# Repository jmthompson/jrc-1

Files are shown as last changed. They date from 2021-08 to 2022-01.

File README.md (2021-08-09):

JRC-1
=====

The JRC-1 (Josh's Retro Computer 1) the first in my new series of homebrew
retro computers. It is the first in the JRC series and is the successor to
COLE-1 and COLE-2.

The primary goal for this project is to scale back some of the lofty goals set
for its predecessor, and instead provide some limited expansion capabilities
so that features can be added iteratively down the road.

More information is available on the JRC-1 section of my blog at
https://www.area73.us/jrc-1.

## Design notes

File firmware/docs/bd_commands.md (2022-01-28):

Block Device Commands
=====================

[I] = input parameter
[O] = output parameter

* INIT ($01)

no command block

* STATUS ($02)

    0 : [O] status, 1 = online, 0 = offline
  1-4 : [O] unit size in blocks
 5-31 : [O] unit name, null-terminated

* MOUNT ($03)

no command block

* EJECT ($04)

no command block

* FORMAT ($05)

no command block

* READ_BLOCK ($06)

0-4 : [I] block number 
5-8 : [I] block buffer pointer

* WRITE_BLOCK ($07)

0-4 : [I] block number 
5-8 : [I] block buffer pointer

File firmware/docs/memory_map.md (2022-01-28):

JRC-1 Memory Map
================

|--------------------------------| $00/0000
|         Base RAM (60K)         |
|--------------------------------| $00/F000
|         I/O Area (2K)          |
|--------------------------------| $00/F800
|         Boot ROM (2K)          |
|--------------------------------| $01/0000
|      Extended RAM (944K)       |
|--------------------------------| $0F/C000
|        Video RAM (16K)         |
|--------------------------------| $10/0000
|       System ROM (256K)        |
|--------------------------------| $14/0000

Due to the way the hardware maps the ROM into the processor address space, the
boot ROM area from $00/F800-FFFF also appears at $10/F800-FFFF. This is where
the code "really" lives in the EEPROM image.

The space in banks $14-$1F are dead space, and will usually just read back as
containing the bank number byte at all locations. At bank $20 and beyond the
memory map just repeats, as A21-A23 are not decoded by the hardware.

* Bank 0

$0000 - $CFFF : [ unused, available for application use ]
$D000 - $E6FF : System buffers
$E700 - $E7FF : System direct page
$E800 - $EFFF : System stack
$F000 - $F7FF : I/O (see table below)
$F800 - $FFFF : Boot ROM (boot/interrupt vectors, I/O drivers)

The I/O is divided into eight 256-byte pages. For each page $FnXX the
value n corresponds to a slot number from 0-7. Slot 0 is for on-board
devices, 1-3 are the three slots on the board, and 4-7 are currently
reserved.

The on-board devices are assigne 16-byte I/O windows in the slot 0 space
as follows:

$F000 - $F00F : VIA
$F010 - $F01F : SPI
$F020 - $F02F : UART

All other space is reserved.

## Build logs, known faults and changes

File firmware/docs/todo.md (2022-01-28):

TODO
====

This is just a scratch space for me to write down things that need
fixed or updated.

- Make BRK handler jump through a RAM vector that we default to being monitor_brk
- Make NMI handler jump through a RAM vector that we default to being monitor_nmi
- Add a user-settable vector for via_irq (or maybe one per interrupt source)

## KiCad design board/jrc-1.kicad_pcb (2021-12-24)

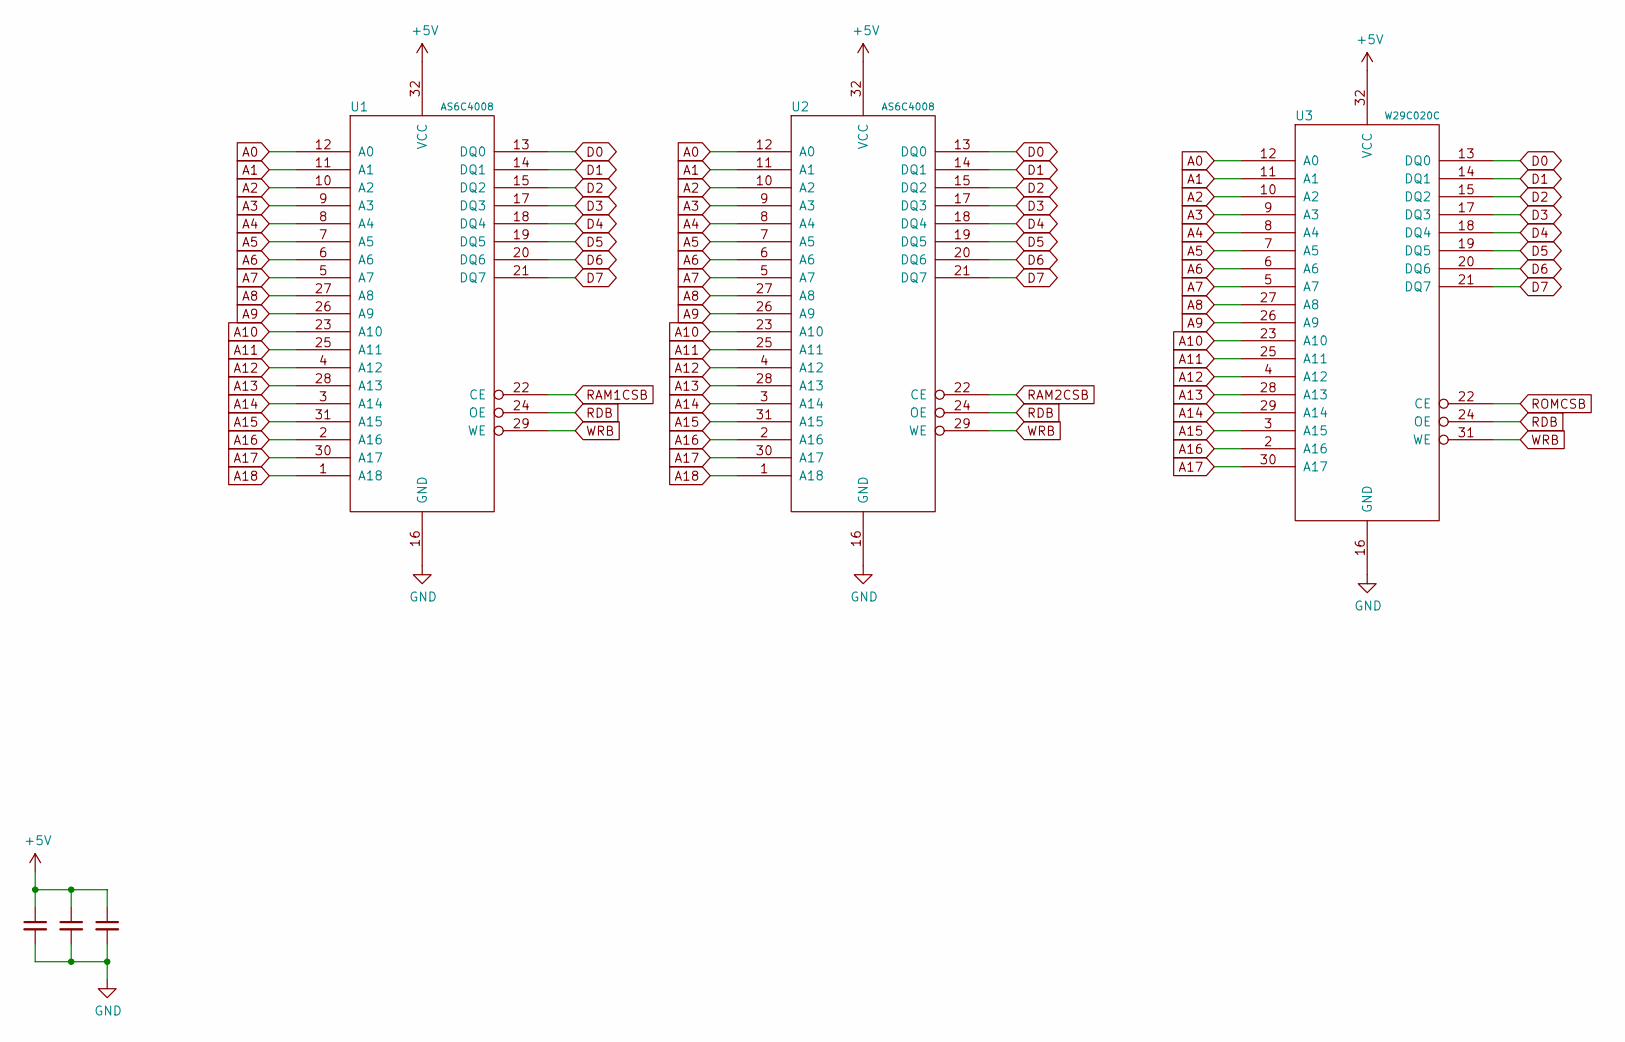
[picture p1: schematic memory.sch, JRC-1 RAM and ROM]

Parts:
C1, C2, C3: 0.1u; C_Rect_L4.6mm_W2.0mm_P2.50mm_MKS02_FKP02
U1, U2: AS6C4008; DIP-32_W15.24mm_Socket
U3: W29C020C; DIP_Socket-32_W11.9_W12.7_W15.24_W17.78_W18.5_3M_232-1285-0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

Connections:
+5V: C1.1, C2.1, C3.1, U1.32 (VCC), U2.32 (VCC), U3.32 (VCC); also elsewhere on the board
A0: U1.12 (A0), U2.12 (A0), U3.12 (A0); also elsewhere on the board
A1: U1.11 (A1), U2.11 (A1), U3.11 (A1); also elsewhere on the board
A2: U1.10 (A2), U2.10 (A2), U3.10 (A2); also elsewhere on the board
A3: U1.9 (A3), U2.9 (A3), U3.9 (A3); also elsewhere on the board
A4: U1.8 (A4), U2.8 (A4), U3.8 (A4); also elsewhere on the board
A5: U1.7 (A5), U2.7 (A5), U3.7 (A5); also elsewhere on the board
A6: U1.6 (A6), U2.6 (A6), U3.6 (A6); also elsewhere on the board
A7: U1.5 (A7), U2.5 (A7), U3.5 (A7); also elsewhere on the board
A8: U1.27 (A8), U2.27 (A8), U3.27 (A8); also elsewhere on the board
A9: U1.26 (A9), U2.26 (A9), U3.26 (A9); also elsewhere on the board
A10: U1.23 (A10), U2.23 (A10), U3.23 (A10); also elsewhere on the board
A11: U1.25 (A11), U2.25 (A11), U3.25 (A11); also elsewhere on the board
A12: U1.4 (A12), U2.4 (A12), U3.4 (A12); also elsewhere on the board
A13: U1.28 (A13), U2.28 (A13), U3.28 (A13); also elsewhere on the board
A14: U1.3 (A14), U2.3 (A14), U3.29 (A14); also elsewhere on the board
A15: U1.31 (A15), U2.31 (A15), U3.3 (A15); also elsewhere on the board
A16: U1.2 (A16), U2.2 (A16), U3.2 (A16); also elsewhere on the board
A17: U1.30 (A17), U2.30 (A17), U3.30 (A17); also elsewhere on the board
A18: U1.1 (A18), U2.1 (A18); also elsewhere on the board
D0: U1.13 (DQ0), U2.13 (DQ0), U3.13 (DQ0); also elsewhere on the board
D1: U1.14 (DQ1), U2.14 (DQ1), U3.14 (DQ1); also elsewhere on the board
D2: U1.15 (DQ2), U2.15 (DQ2), U3.15 (DQ2); also elsewhere on the board
D3: U1.17 (DQ3), U2.17 (DQ3), U3.17 (DQ3); also elsewhere on the board
D4: U1.18 (DQ4), U2.18 (DQ4), U3.18 (DQ4); also elsewhere on the board
D5: U1.19 (DQ5), U2.19 (DQ5), U3.19 (DQ5); also elsewhere on the board
D6: U1.20 (DQ6), U2.20 (DQ6), U3.20 (DQ6); also elsewhere on the board
D7: U1.21 (DQ7), U2.21 (DQ7), U3.21 (DQ7); also elsewhere on the board
GND: C1.2, C2.2, C3.2, U1.16 (GND), U2.16 (GND), U3.16 (GND); also elsewhere on the board
RAM1CSB: U1.22 (CE); also elsewhere on the board
RAM2CSB: U2.22 (CE); also elsewhere on the board
RDB: U1.24 (OE), U2.24 (OE), U3.24 (OE); also elsewhere on the board
ROMCSB: U3.22 (CE); also elsewhere on the board
WRB: U1.29 (WE), U2.29 (WE), U3.31 (WE); also elsewhere on the board

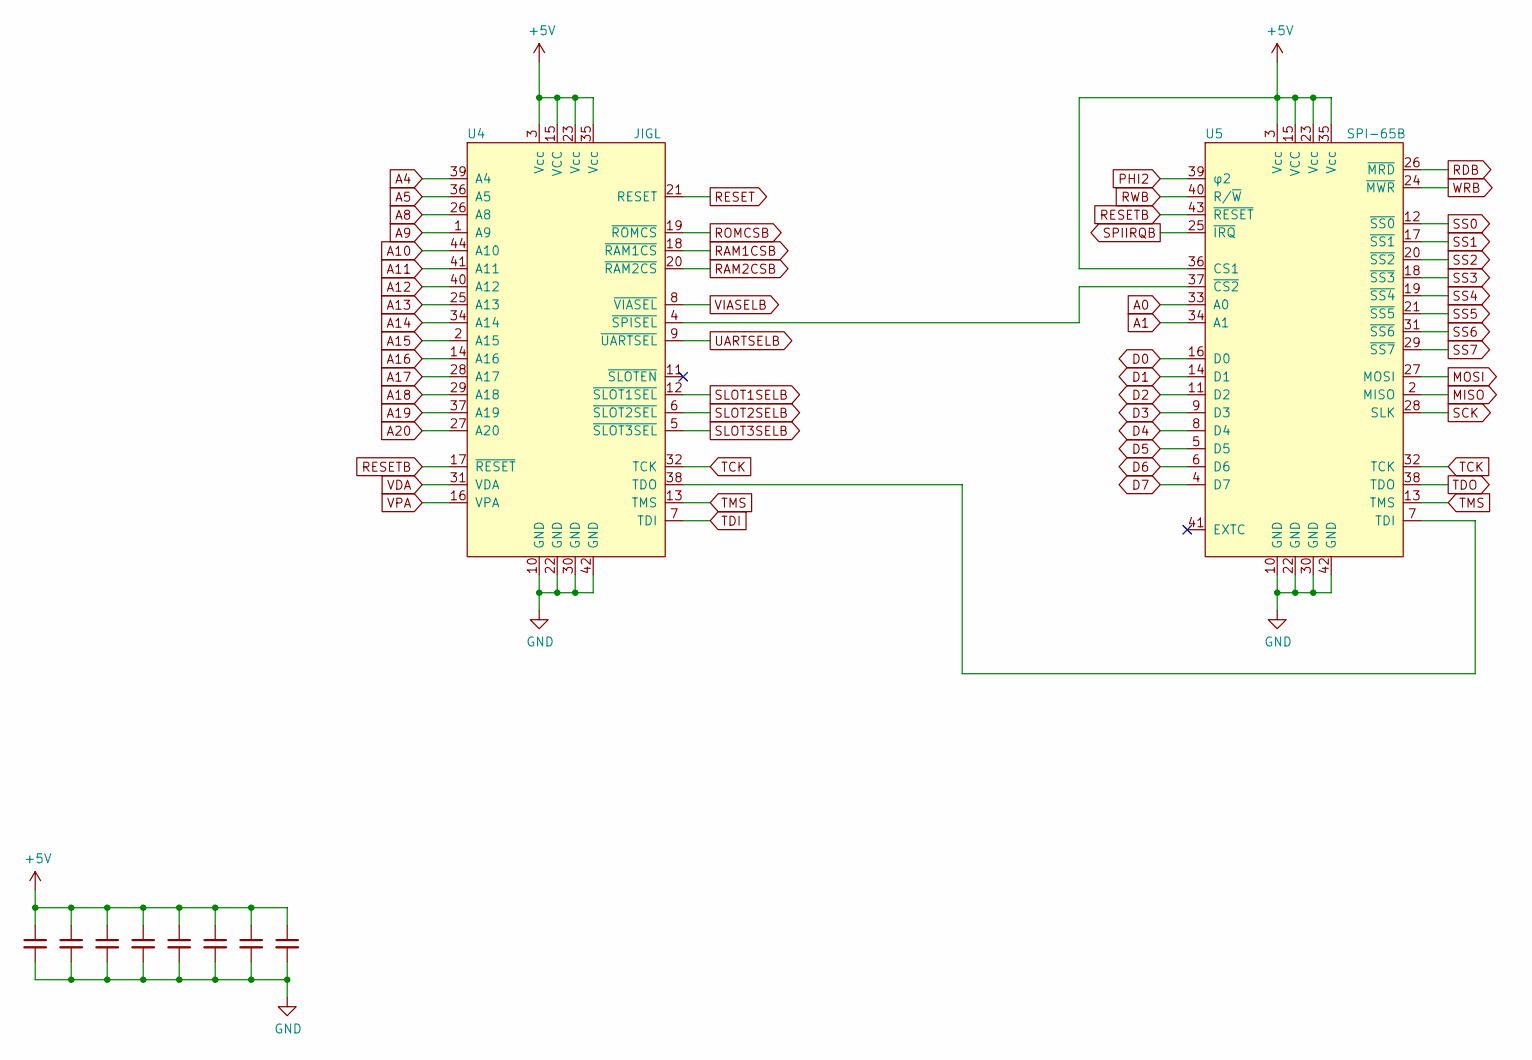
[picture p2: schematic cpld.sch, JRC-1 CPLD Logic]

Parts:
C4, C5, C6, C7, C8, C9, C10, C11: 0.1u; C_Rect_L4.6mm_W2.0mm_P2.50mm_MKS02_FKP02
U4: JIGL; PLCC-44_THT-Socket
U5: SPI-65B; PLCC-44_THT-Socket

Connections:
+5V: C4.1, C5.1, C6.1, C7.1, C8.1, C9.1, C10.1, C11.1, U4.3 (Vcc), U4.15 (VCC), U4.23 (Vcc), U4.35 (Vcc), U5.3 (Vcc), U5.15 (VCC), U5.23 (Vcc), U5.35 (Vcc), U5.36 (CS1); also elsewhere on the board
A0: U5.33 (A0); also elsewhere on the board
A1: U5.34 (A1); also elsewhere on the board
A4: U4.39 (A4); also elsewhere on the board
A5: U4.36 (A5); also elsewhere on the board
A8: U4.26 (A8); also elsewhere on the board
A9: U4.1 (A9); also elsewhere on the board
A10: U4.44 (A10); also elsewhere on the board
A11: U4.41 (A11); also elsewhere on the board
A12: U4.40 (A12); also elsewhere on the board
A13: U4.25 (A13); also elsewhere on the board
A14: U4.34 (A14); also elsewhere on the board
A15: U4.2 (A15); also elsewhere on the board
A16: U4.14 (A16); also elsewhere on the board
A17: U4.28 (A17); also elsewhere on the board
A18: U4.29 (A18); also elsewhere on the board
A19: U4.37 (A19); also elsewhere on the board
A20: U4.27 (A20); also elsewhere on the board
D0: U5.16 (D0); also elsewhere on the board
D1: U5.14 (D1); also elsewhere on the board
D2: U5.11 (D2); also elsewhere on the board
D3: U5.9 (D3); also elsewhere on the board
D4: U5.8 (D4); also elsewhere on the board
D5: U5.5 (D5); also elsewhere on the board
D6: U5.6 (D6); also elsewhere on the board
D7: U5.4 (D7); also elsewhere on the board
GND: C4.2, C5.2, C6.2, C7.2, C8.2, C9.2, C10.2, C11.2, U4.10 (GND), U4.22 (GND), U4.30 (GND), U4.42 (GND), U5.10 (GND), U5.22 (GND), U5.30 (GND), U5.42 (GND); also elsewhere on the board
MISO: U5.2 (MISO); also elsewhere on the board
MOSI: U5.27 (MOSI); also elsewhere on the board
unnamed: U4.4 (~SPISEL), U5.37 (~CS2)
unnamed: U4.38 (TDO), U5.7 (TDI)
PHI2: U5.39 (φ2); also elsewhere on the board
RAM1CSB: U4.18 (~RAM1CS); also elsewhere on the board
RAM2CSB: U4.20 (~RAM2CS); also elsewhere on the board
RDB: U5.26 (~MRD); also elsewhere on the board
RESET: U4.21 (RESET); also elsewhere on the board
RESETB: U4.17 (~RESET), U5.43 (~RESET); also elsewhere on the board
ROMCSB: U4.19 (~ROMCS); also elsewhere on the board
RWB: U5.40 (R/~W); also elsewhere on the board
SCK: U5.28 (SLK); also elsewhere on the board
SLOT1SELB: U4.12 (~SLOT1SEL); also elsewhere on the board
SLOT2SELB: U4.6 (~SLOT2SEL); also elsewhere on the board
SLOT3SELB: U4.5 (~SLOT3SEL); also elsewhere on the board
SPIIRQB: U5.25 (~IRQ); also elsewhere on the board
SS0: U5.12 (~SS0); also elsewhere on the board
SS1: U5.17 (~SS1); also elsewhere on the board
SS2: U5.20 (~SS2); also elsewhere on the board
SS3: U5.18 (~SS3); also elsewhere on the board
SS4: U5.19 (~SS4); also elsewhere on the board
SS5: U5.21 (~SS5); also elsewhere on the board
SS6: U5.31 (~SS6); also elsewhere on the board
SS7: U5.29 (~SS7); also elsewhere on the board
TCK: U4.32 (TCK), U5.32 (TCK); also elsewhere on the board
TDI: U4.7 (TDI); also elsewhere on the board
TDO: U5.38 (TDO); also elsewhere on the board
TMS: U4.13 (TMS), U5.13 (TMS); also elsewhere on the board
UARTSELB: U4.9 (~UARTSEL); also elsewhere on the board
VDA: U4.31 (VDA); also elsewhere on the board
VIASELB: U4.8 (~VIASEL); also elsewhere on the board
VPA: U4.16 (VPA); also elsewhere on the board
WRB: U5.24 (~MWR); also elsewhere on the board

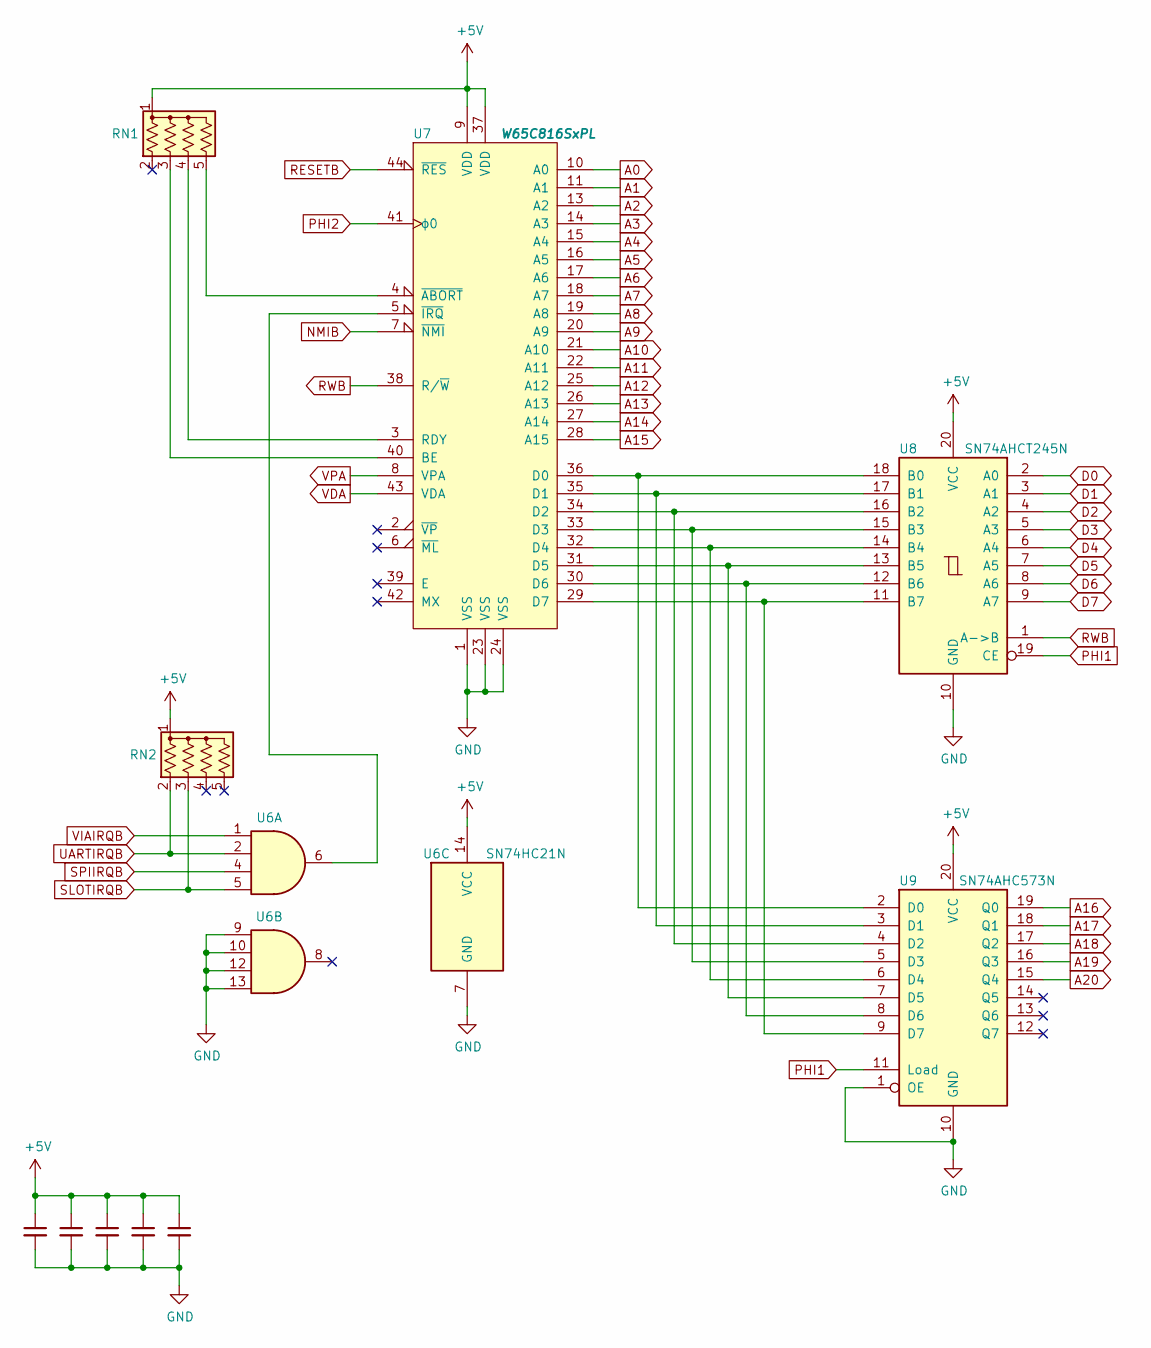
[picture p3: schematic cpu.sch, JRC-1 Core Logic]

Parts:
C12, C13, C14, C15, C16: 0.1u; C_Rect_L4.6mm_W2.0mm_P2.50mm_MKS02_FKP02
RN1, RN2: 4605X-101-332LF; R_Array_SIP5
U6: SN74HC21N; DIP-14_W7.62mm_Socket
U7: W65C816SxPL; PLCC-44_THT-Socket
U8: SN74AHCT245N; DIP-20_W7.62mm_Socket
U9: SN74AHC573N; DIP-20_W7.62mm_Socket

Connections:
+5V: C12.1, C13.1, C14.1, C15.1, C16.1, RN1.1 (common), RN2.1 (common), U6.14 (VCC), U7.9 (VDD), U7.37 (VDD), U8.20 (VCC), U9.20 (VCC); also elsewhere on the board
A0: U7.10 (A0); also elsewhere on the board
A1: U7.11 (A1); also elsewhere on the board
A2: U7.13 (A2); also elsewhere on the board
A3: U7.14 (A3); also elsewhere on the board
A4: U7.15 (A4); also elsewhere on the board
A5: U7.16 (A5); also elsewhere on the board
A6: U7.17 (A6); also elsewhere on the board
A7: U7.18 (A7); also elsewhere on the board
A8: U7.19 (A8); also elsewhere on the board
A9: U7.20 (A9); also elsewhere on the board
A10: U7.21 (A10); also elsewhere on the board
A11: U7.22 (A11); also elsewhere on the board
A12: U7.25 (A12); also elsewhere on the board
A13: U7.26 (A13); also elsewhere on the board
A14: U7.27 (A14); also elsewhere on the board
A15: U7.28 (A15); also elsewhere on the board
A16: U9.19 (Q0); also elsewhere on the board
A17: U9.18 (Q1); also elsewhere on the board
A18: U9.17 (Q2); also elsewhere on the board
A19: U9.16 (Q3); also elsewhere on the board
A20: U9.15 (Q4); also elsewhere on the board
D0: U8.2 (A0); also elsewhere on the board
D1: U8.3 (A1); also elsewhere on the board
D2: U8.4 (A2); also elsewhere on the board
D3: U8.5 (A3); also elsewhere on the board
D4: U8.6 (A4); also elsewhere on the board
D5: U8.7 (A5); also elsewhere on the board
D6: U8.8 (A6); also elsewhere on the board
D7: U8.9 (A7); also elsewhere on the board
GND: C12.2, C13.2, C14.2, C15.2, C16.2, U6.7 (GND), U6.9, U6.10, U6.12, U6.13, U7.1 (VSS), U7.23 (VSS), U7.24 (VSS), U8.10 (GND), U9.1 (OE), U9.10 (GND); also elsewhere on the board
NMIB: U7.7 (~NMI); also elsewhere on the board
unnamed: RN1.3 (R2), U7.40 (BE)
unnamed: RN1.4 (R3), U7.3 (RDY)
unnamed: RN1.5 (R4), U7.4 (~ABORT)
unnamed: U6.6, U7.5 (~IRQ)
unnamed: U7.29 (D7), U8.11 (B7), U9.9 (D7)
unnamed: U7.30 (D6), U8.12 (B6), U9.8 (D6)
unnamed: U7.31 (D5), U8.13 (B5), U9.7 (D5)
unnamed: U7.32 (D4), U8.14 (B4), U9.6 (D4)
unnamed: U7.33 (D3), U8.15 (B3), U9.5 (D3)
unnamed: U7.34 (D2), U8.16 (B2), U9.4 (D2)
unnamed: U7.35 (D1), U8.17 (B1), U9.3 (D1)
unnamed: U7.36 (D0), U8.18 (B0), U9.2 (D0)
PHI1: U8.19 (CE), U9.11 (Load); also elsewhere on the board
PHI2: U7.41 (ϕ0); also elsewhere on the board
RESETB: U7.44 (~RES); also elsewhere on the board
RWB: U7.38 (R/~W), U8.1 (A->B); also elsewhere on the board
SLOTIRQB: RN2.3 (R2), U6.5; also elsewhere on the board
SPIIRQB: U6.4; also elsewhere on the board
UARTIRQB: RN2.2 (R1), U6.2; also elsewhere on the board
VDA: U7.43 (VDA); also elsewhere on the board
VIAIRQB: U6.1; also elsewhere on the board
VPA: U7.8 (VPA); also elsewhere on the board

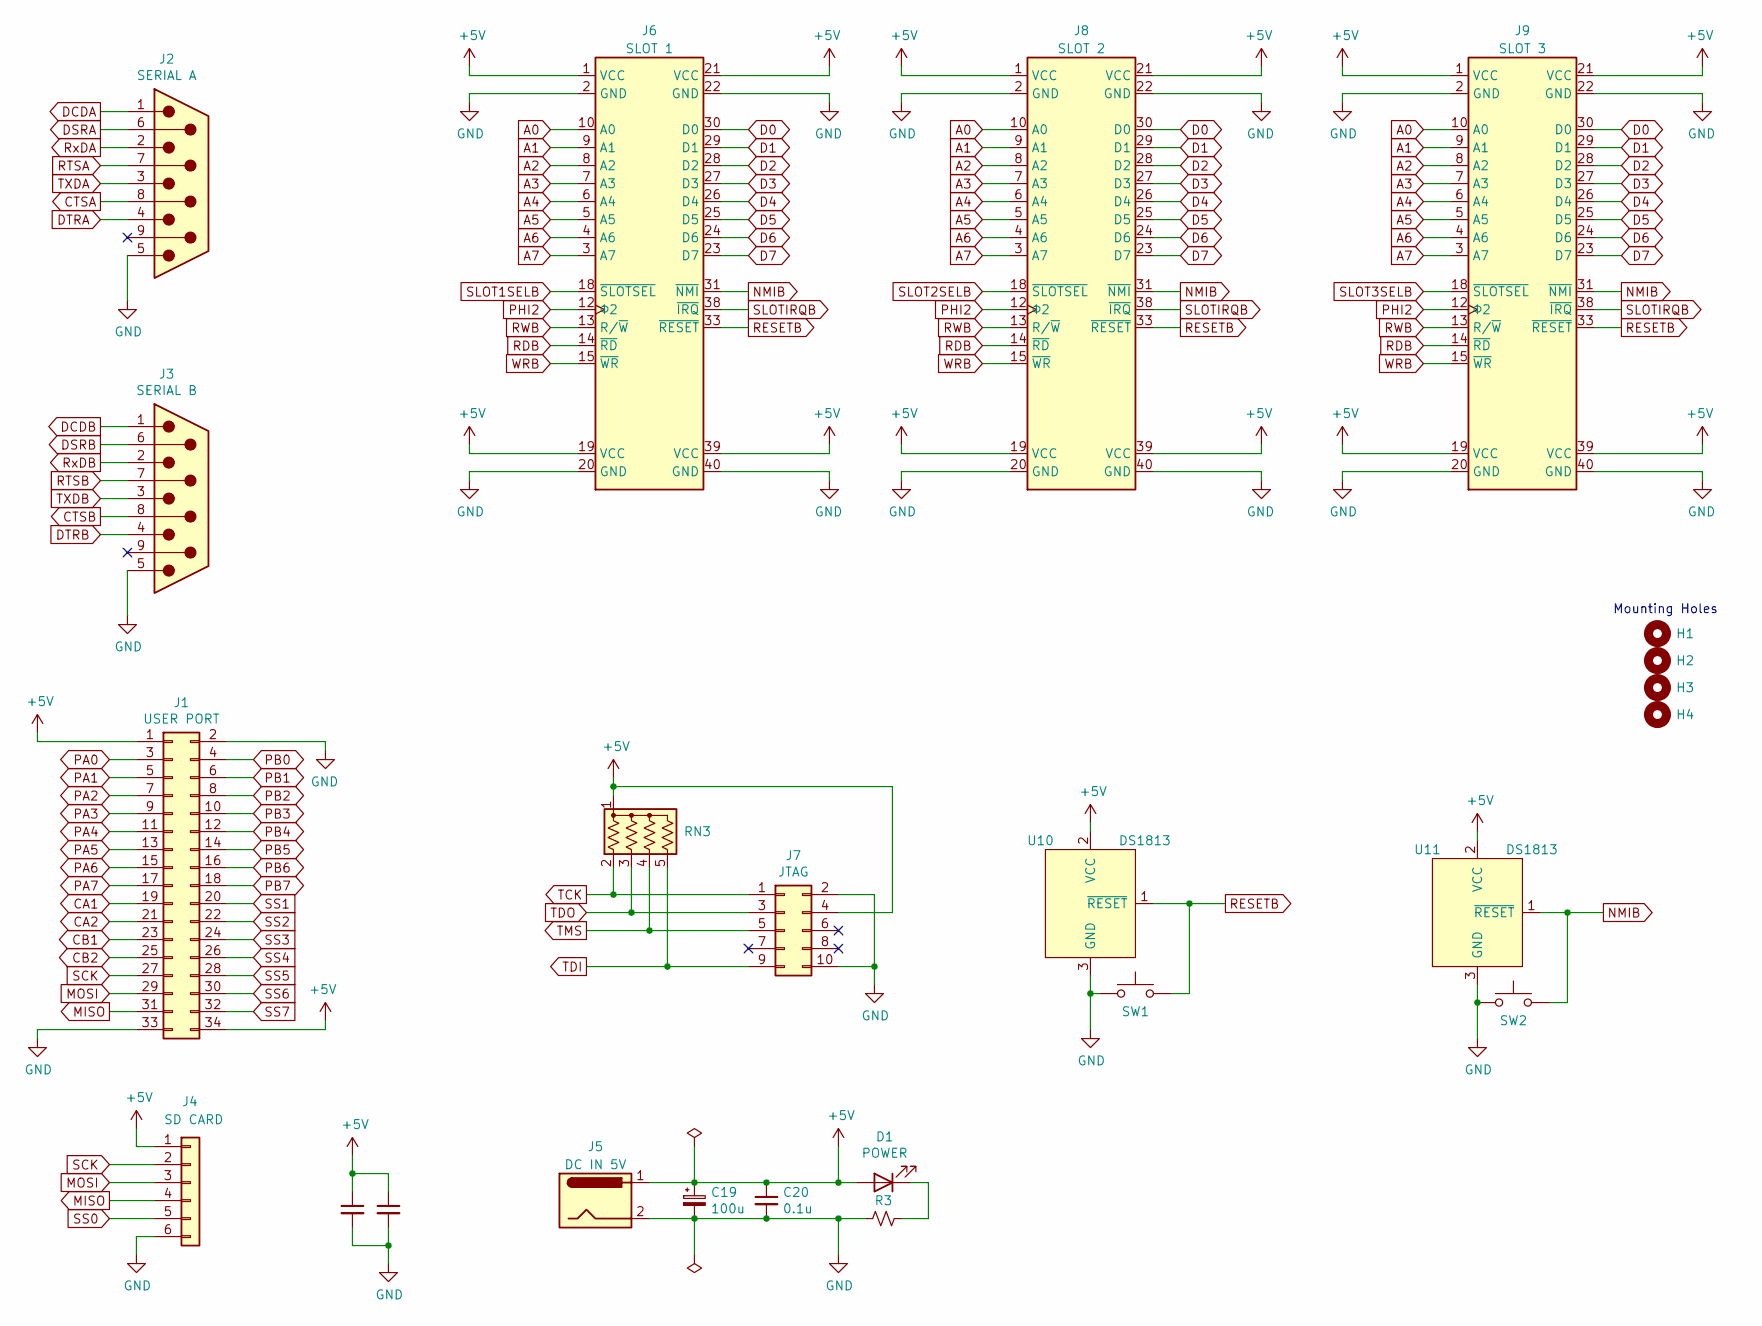
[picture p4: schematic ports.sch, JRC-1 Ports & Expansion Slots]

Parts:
C17, C18, C20: 0.1u; C_Rect_L4.6mm_W2.0mm_P2.50mm_MKS02_FKP02
C19: 100u; CP_Radial_D6.3mm_P2.50mm
D1: POWER; LED_D5.0mm_Clear
H1, H2, H3, H4: MountingHole; MountingHole_2.7mm_M2.5
J1: USER PORT; PinHeader_2x17_P2.54mm_Vertical
J2: SERIAL A; DSUB-9_Male_Horizontal_P2.77x2.84mm_EdgePinOffset4.94mm_Hou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
J3: SERIAL B; DSUB-9_Male_Horizontal_P2.77x2.84mm_EdgePinOffset4.94mm_Hou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
J4: SD CARD; PinHeader_1x06_P2.54mm_Vertical
J5: DC IN 5V; BarrelJack_Horizontal
J6: SLOT 1; JRC_Expansion_Slot
J7: JTAG; IDC-Header_2x05_P2.54mm_Vertical
J8: SLOT 2; JRC_Expansion_Slot
J9: SLOT 3; JRC_Expansion_Slot
R3: 330; R_Axial_DIN0207_L6.3mm_D2.5mm_P10.16mm_Horizontal
RN3: 4605X-101-472LF; R_Array_SIP5
SW1: RESET; SW_PUSH_6mm_H5mm
SW2: NMI; SW_PUSH_6mm_H5mm
U10, U11: DS1813; TO-92

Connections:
+5V: C17.1, C18.1, C19.1, C20.1, D1.2 (A), J1.1, J1.34, J4.1, J5.1, J6.1 (VCC), J6.19 (VCC), J6.21 (VCC), J6.39 (VCC), J7.4, J8.1 (VCC), J8.19 (VCC), J8.21 (VCC), J8.39 (VCC), J9.1 (VCC), J9.19 (VCC), J9.21 (VCC), J9.39 (VCC), RN3.1 (common), U10.2 (VCC), U11.2 (VCC); also elsewhere on the board
A0: J6.10 (A0), J8.10 (A0), J9.10 (A0); also elsewhere on the board
A1: J6.9 (A1), J8.9 (A1), J9.9 (A1); also elsewhere on the board
A2: J6.8 (A2), J8.8 (A2), J9.8 (A2); also elsewhere on the board
A3: J6.7 (A3), J8.7 (A3), J9.7 (A3); also elsewhere on the board
A4: J6.6 (A4), J8.6 (A4), J9.6 (A4); also elsewhere on the board
A5: J6.5 (A5), J8.5 (A5), J9.5 (A5); also elsewhere on the board
A6: J6.4 (A6), J8.4 (A6), J9.4 (A6); also elsewhere on the board
A7: J6.3 (A7), J8.3 (A7), J9.3 (A7); also elsewhere on the board
CA1: J1.19; also elsewhere on the board
CA2: J1.21; also elsewhere on the board
CB1: J1.23; also elsewhere on the board
CB2: J1.25; also elsewhere on the board
CTSA: J2.8; also elsewhere on the board
CTSB: J3.8; also elsewhere on the board
D0: J6.30 (D0), J8.30 (D0), J9.30 (D0); also elsewhere on the board
D1: J6.29 (D1), J8.29 (D1), J9.29 (D1); also elsewhere on the board
D2: J6.28 (D2), J8.28 (D2), J9.28 (D2); also elsewhere on the board
D3: J6.27 (D3), J8.27 (D3), J9.27 (D3); also elsewhere on the board
D4: J6.26 (D4), J8.26 (D4), J9.26 (D4); also elsewhere on the board
D5: J6.25 (D5), J8.25 (D5), J9.25 (D5); also elsewhere on the board
D6: J6.24 (D6), J8.24 (D6), J9.24 (D6); also elsewhere on the board
D7: J6.23 (D7), J8.23 (D7), J9.23 (D7); also elsewhere on the board
DCDA: J2.1; also elsewhere on the board
DCDB: J3.1; also elsewhere on the board
DSRA: J2.6; also elsewhere on the board
DSRB: J3.6; also elsewhere on the board
DTRA: J2.4; also elsewhere on the board
DTRB: J3.4; also elsewhere on the board
GND: C17.2, C18.2, C19.2, C20.2, J1.2, J1.33, J2.5, J3.5, J4.6, J5.2, J6.2 (GND), J6.20 (GND), J6.22 (GND), J6.40 (GND), J7.2, J7.10, J8.2 (GND), J8.20 (GND), J8.22 (GND), J8.40 (GND), J9.2 (GND), J9.20 (GND), J9.22 (GND), J9.40 (GND), R3.2, SW1.1, SW2.1, U10.3 (GND), U11.3 (GND); also elsewhere on the board
MISO: J1.31, J4.4; also elsewhere on the board
MOSI: J1.29, J4.3; also elsewhere on the board
NMIB: J6.31 (~NMI), J8.31 (~NMI), J9.31 (~NMI), SW2.2, U11.1 (~RESET); also elsewhere on the board
unnamed: D1.1 (K), R3.1
PA0: J1.3; also elsewhere on the board
PA1: J1.5; also elsewhere on the board
PA2: J1.7; also elsewhere on the board
PA3: J1.9; also elsewhere on the board
PA4: J1.11; also elsewhere on the board
PA5: J1.13; also elsewhere on the board
PA6: J1.15; also elsewhere on the board
PA7: J1.17; also elsewhere on the board
PB0: J1.4; also elsewhere on the board
PB1: J1.6; also elsewhere on the board
PB2: J1.8; also elsewhere on the board
PB3: J1.10; also elsewhere on the board
PB4: J1.12; also elsewhere on the board
PB5: J1.14; also elsewhere on the board
PB6: J1.16; also elsewhere on the board
PB7: J1.18; also elsewhere on the board
PHI2: J6.12 (Φ2), J8.12 (Φ2), J9.12 (Φ2); also elsewhere on the board
RDB: J6.14 (~RD), J8.14 (~RD), J9.14 (~RD); also elsewhere on the board
RESETB: J6.33 (~RESET), J8.33 (~RESET), J9.33 (~RESET), SW1.2, U10.1 (~RESET); also elsewhere on the board
RTSA: J2.7; also elsewhere on the board
RTSB: J3.7; also elsewhere on the board
RWB: J6.13 (R/~W), J8.13 (R/~W), J9.13 (R/~W); also elsewhere on the board
RxDA: J2.2; also elsewhere on the board
RxDB: J3.2; also elsewhere on the board
SCK: J1.27, J4.2; also elsewhere on the board
SLOT1SELB: J6.18 (~SLOTSEL); also elsewhere on the board
SLOT2SELB: J8.18 (~SLOTSEL); also elsewhere on the board
SLOT3SELB: J9.18 (~SLOTSEL); also elsewhere on the board
SLOTIRQB: J6.38 (~IRQ), J8.38 (~IRQ), J9.38 (~IRQ); also elsewhere on the board
SS0: J4.5; also elsewhere on the board
SS1: J1.20; also elsewhere on the board
SS2: J1.22; also elsewhere on the board
SS3: J1.24; also elsewhere on the board
SS4: J1.26; also elsewhere on the board
SS5: J1.28; also elsewhere on the board
SS6: J1.30; also elsewhere on the board
SS7: J1.32; also elsewhere on the board
TCK: J7.1, RN3.2 (R1); also elsewhere on the board
TDI: J7.9, RN3.5 (R4); also elsewhere on the board
TDO: J7.3, RN3.3 (R2); also elsewhere on the board
TMS: J7.5, RN3.4 (R3); also elsewhere on the board
TXDA: J2.3; also elsewhere on the board
TXDB: J3.3; also elsewhere on the board
WRB: J6.15 (~WR), J8.15 (~WR), J9.15 (~WR); also elsewhere on the board

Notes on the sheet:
Mounting Holes

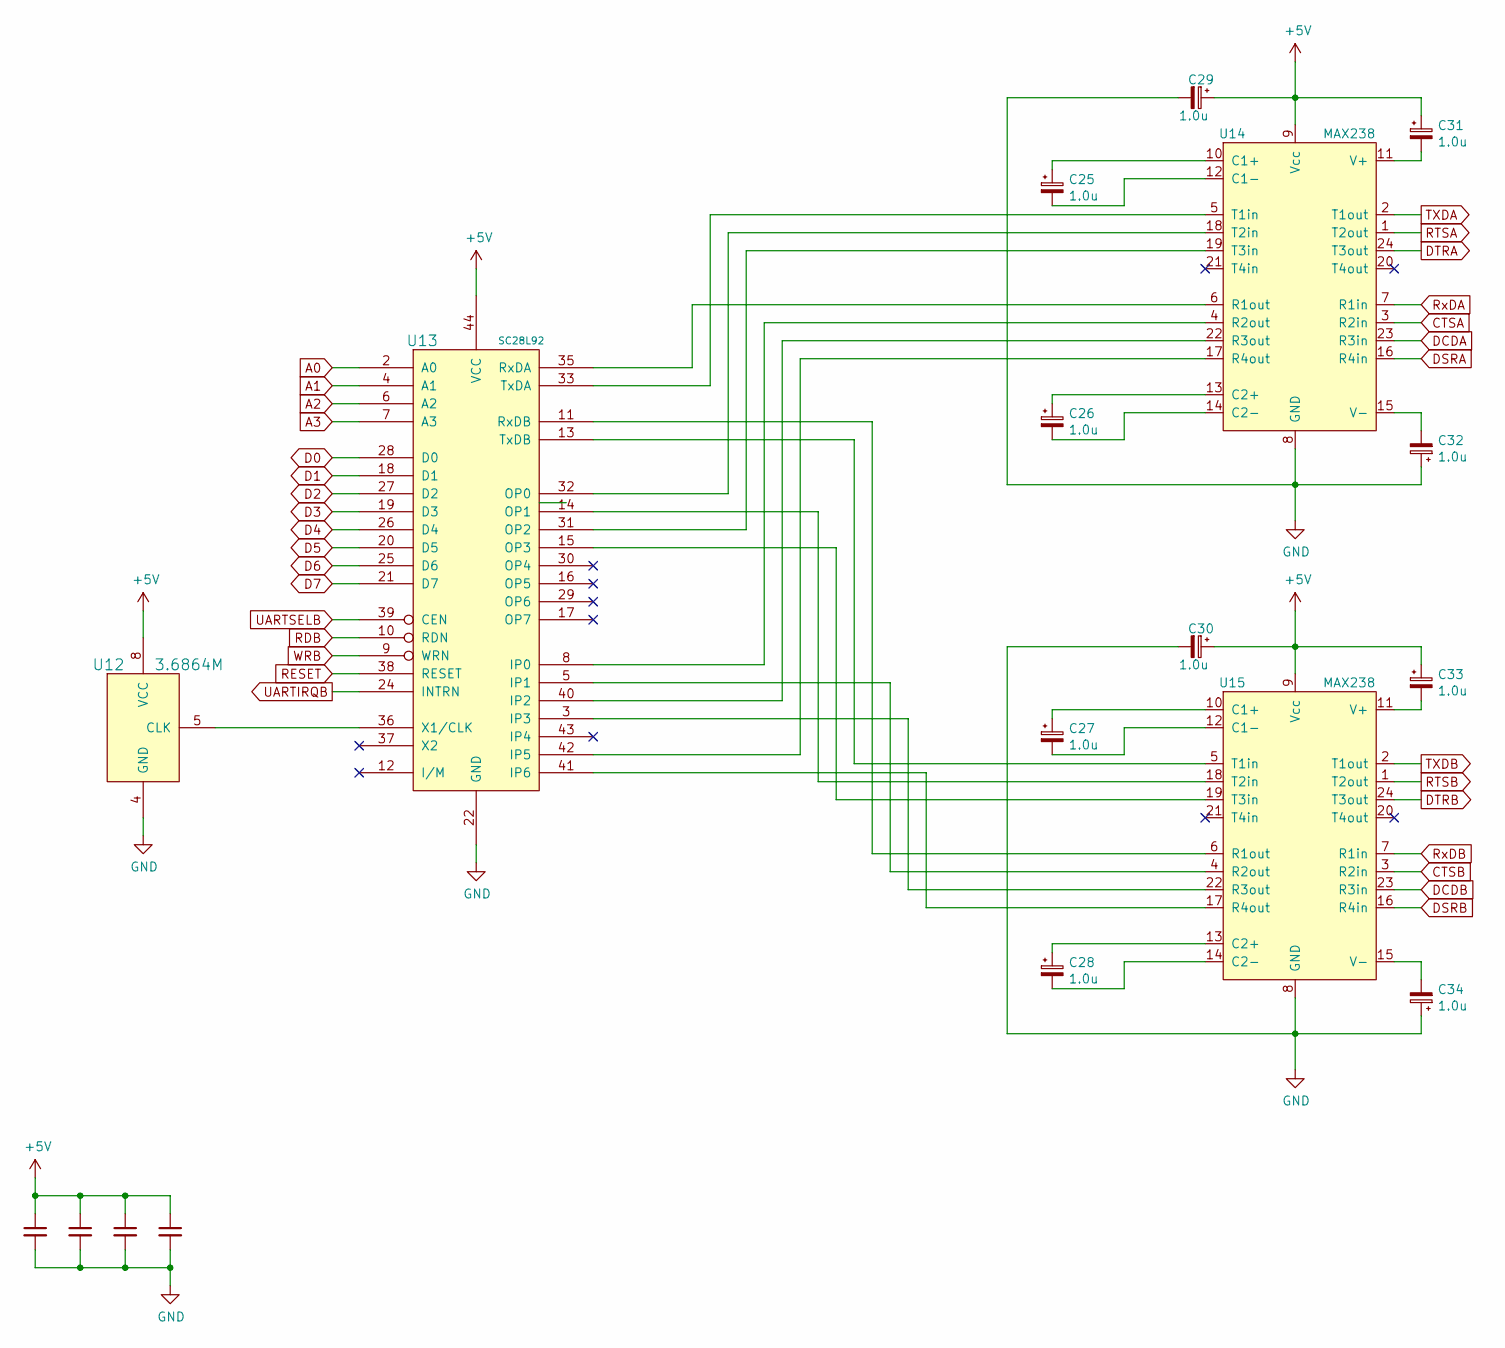
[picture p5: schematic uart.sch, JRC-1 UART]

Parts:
C21, C22, C23, C24: 0.1u; C_Rect_L4.6mm_W2.0mm_P2.50mm_MKS02_FKP02
C25, C26, C27, C28, C29, C30, C31, C32, C33, C34: 1.0u; CP_Radial_D5.0mm_P2.00mm
U12: 3.6864M; DIP-8_W7.62mm_Socket
U13: SC28L92; PLCC-44_THT-Socket
U14, U15: MAX238; DIP-24_W7.62mm_Socket

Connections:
+5V: C21.1, C22.1, C23.1, C24.1, C29.1, C30.1, C31.1, C33.1, U12.8 (VCC), U13.44 (VCC), U14.9 (Vcc), U15.9 (Vcc); also elsewhere on the board
A0: U13.2 (A0); also elsewhere on the board
A1: U13.4 (A1); also elsewhere on the board
A2: U13.6 (A2); also elsewhere on the board
A3: U13.7 (A3); also elsewhere on the board
CTSA: U14.3 (R2in); also elsewhere on the board
CTSB: U15.3 (R2in); also elsewhere on the board
D0: U13.28 (D0); also elsewhere on the board
D1: U13.18 (D1); also elsewhere on the board
D2: U13.27 (D2); also elsewhere on the board
D3: U13.19 (D3); also elsewhere on the board
D4: U13.26 (D4); also elsewhere on the board
D5: U13.20 (D5); also elsewhere on the board
D6: U13.25 (D6); also elsewhere on the board
D7: U13.21 (D7); also elsewhere on the board
DCDA: U14.23 (R3in); also elsewhere on the board
DCDB: U15.23 (R3in); also elsewhere on the board
DSRA: U14.16 (R4in); also elsewhere on the board
DSRB: U15.16 (R4in); also elsewhere on the board
DTRA: U14.24 (T3out); also elsewhere on the board
DTRB: U15.24 (T3out); also elsewhere on the board
GND: C21.2, C22.2, C23.2, C24.2, C29.2, C30.2, C32.1, C34.1, U12.4 (GND), U13.22 (GND), U14.8 (GND), U15.8 (GND); also elsewhere on the board
unnamed: C25.1, U14.10 (C1+)
unnamed: C25.2, U14.12 (C1-)
unnamed: C26.1, U14.13 (C2+)
unnamed: C26.2, U14.14 (C2-)
unnamed: C27.1, U15.10 (C1+)
unnamed: C27.2, U15.12 (C1-)
unnamed: C28.1, U15.13 (C2+)
unnamed: C28.2, U15.14 (C2-)
unnamed: C31.2, U14.11 (V+)
unnamed: C32.2, U14.15 (V-)
unnamed: C33.2, U15.11 (V+)
unnamed: C34.2, U15.15 (V-)
unnamed: U12.5 (CLK), U13.36 (X1/CLK)
unnamed: U13.3 (IP3), U15.22 (R3out)
unnamed: U13.5 (IP1), U15.4 (R2out)
unnamed: U13.8 (IP0), U14.4 (R2out)
unnamed: U13.11 (RxDB), U15.6 (R1out)
unnamed: U13.13 (TxDB), U15.5 (T1in)
unnamed: U13.14 (OP1), U15.18 (T2in)
unnamed: U13.15 (OP3), U15.19 (T3in)
unnamed: U13.31 (OP2), U14.19 (T3in)
unnamed: U13.32 (OP0), U14.18 (T2in)
unnamed: U13.33 (TxDA), U14.5 (T1in)
unnamed: U13.35 (RxDA), U14.6 (R1out)
unnamed: U13.40 (IP2), U14.22 (R3out)
unnamed: U13.41 (IP6), U15.17 (R4out)
unnamed: U13.42 (IP5), U14.17 (R4out)
RDB: U13.10 (RDN); also elsewhere on the board
RESET: U13.38 (RESET); also elsewhere on the board
RTSA: U14.1 (T2out); also elsewhere on the board
RTSB: U15.1 (T2out); also elsewhere on the board
RxDA: U14.7 (R1in); also elsewhere on the board
RxDB: U15.7 (R1in); also elsewhere on the board
TXDA: U14.2 (T1out); also elsewhere on the board
TXDB: U15.2 (T1out); also elsewhere on the board
UARTIRQB: U13.24 (INTRN); also elsewhere on the board
UARTSELB: U13.39 (CEN); also elsewhere on the board
WRB: U13.9 (WRN); also elsewhere on the board

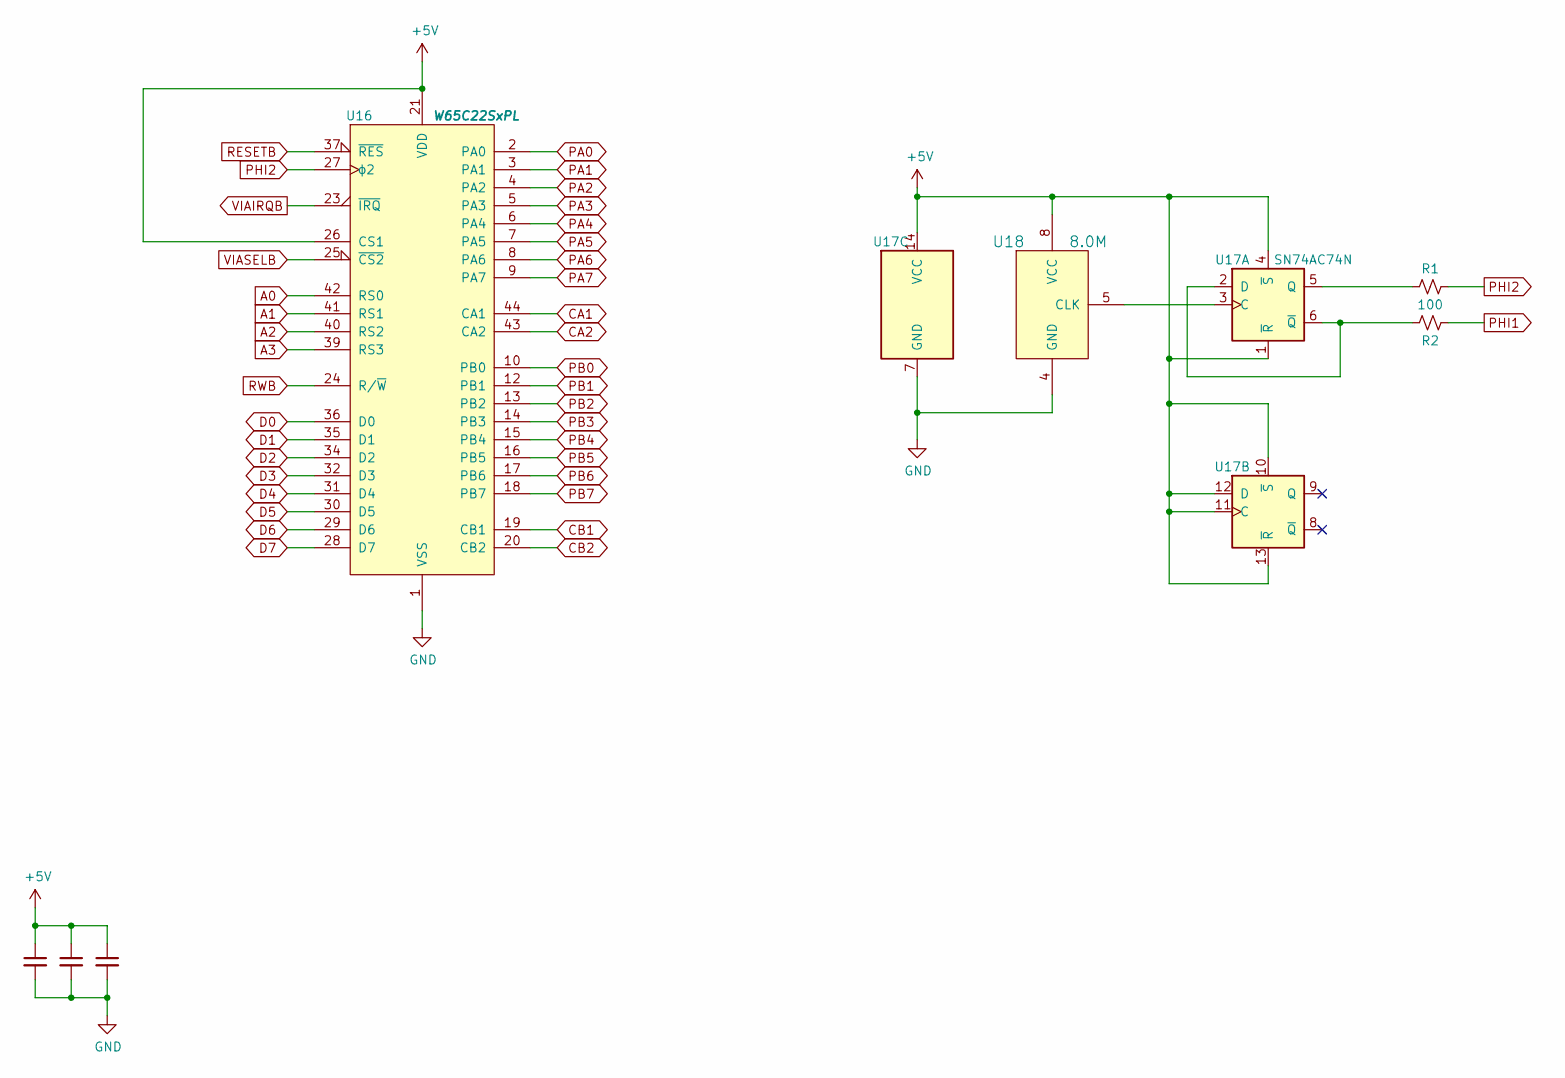
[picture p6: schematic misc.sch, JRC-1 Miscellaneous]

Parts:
C35, C36, C37: 0.1u; C_Rect_L4.6mm_W2.0mm_P2.50mm_MKS02_FKP02
R1, R2: 100; R_Axial_DIN0207_L6.3mm_D2.5mm_P10.16mm_Horizontal
U16: W65C22SxPL; PLCC-44_THT-Socket
U17: SN74AC74N; DIP-14_W7.62mm_Socket
U18: 8.0M; DIP-8_W7.62mm_Socket

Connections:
+5V: C35.1, C36.1, C37.1, U16.21 (VDD), U16.26 (CS1), U17.1 (~R), U17.4 (~S), U17.10 (~S), U17.11 (C), U17.12 (D), U17.13 (~R), U17.14 (VCC), U18.8 (VCC); also elsewhere on the board
A0: U16.42 (RS0); also elsewhere on the board
A1: U16.41 (RS1); also elsewhere on the board
A2: U16.40 (RS2); also elsewhere on the board
A3: U16.39 (RS3); also elsewhere on the board
CA1: U16.44 (CA1); also elsewhere on the board
CA2: U16.43 (CA2); also elsewhere on the board
CB1: U16.19 (CB1); also elsewhere on the board
CB2: U16.20 (CB2); also elsewhere on the board
D0: U16.36 (D0); also elsewhere on the board
D1: U16.35 (D1); also elsewhere on the board
D2: U16.34 (D2); also elsewhere on the board
D3: U16.32 (D3); also elsewhere on the board
D4: U16.31 (D4); also elsewhere on the board
D5: U16.30 (D5); also elsewhere on the board
D6: U16.29 (D6); also elsewhere on the board
D7: U16.28 (D7); also elsewhere on the board
GND: C35.2, C36.2, C37.2, U16.1 (VSS), U17.7 (GND), U18.4 (GND); also elsewhere on the board
unnamed: R1.2, U17.5 (Q)
unnamed: R2.2, U17.2 (D), U17.6 (~Q)
unnamed: U17.3 (C), U18.5 (CLK)
PA0: U16.2 (PA0); also elsewhere on the board
PA1: U16.3 (PA1); also elsewhere on the board
PA2: U16.4 (PA2); also elsewhere on the board
PA3: U16.5 (PA3); also elsewhere on the board
PA4: U16.6 (PA4); also elsewhere on the board
PA5: U16.7 (PA5); also elsewhere on the board
PA6: U16.8 (PA6); also elsewhere on the board
PA7: U16.9 (PA7); also elsewhere on the board
PB0: U16.10 (PB0); also elsewhere on the board
PB1: U16.12 (PB1); also elsewhere on the board
PB2: U16.13 (PB2); also elsewhere on the board
PB3: U16.14 (PB3); also elsewhere on the board
PB4: U16.15 (PB4); also elsewhere on the board
PB5: U16.16 (PB5); also elsewhere on the board
PB6: U16.17 (PB6); also elsewhere on the board
PB7: U16.18 (PB7); also elsewhere on the board
PHI1: R2.1; also elsewhere on the board
PHI2: R1.1, U16.27 (ϕ2); also elsewhere on the board
RESETB: U16.37 (~RES); also elsewhere on the board
RWB: U16.24 (R/~W); also elsewhere on the board
VIAIRQB: U16.23 (~IRQ); also elsewhere on the board
VIASELB: U16.25 (~CS2); also elsewhere on the board

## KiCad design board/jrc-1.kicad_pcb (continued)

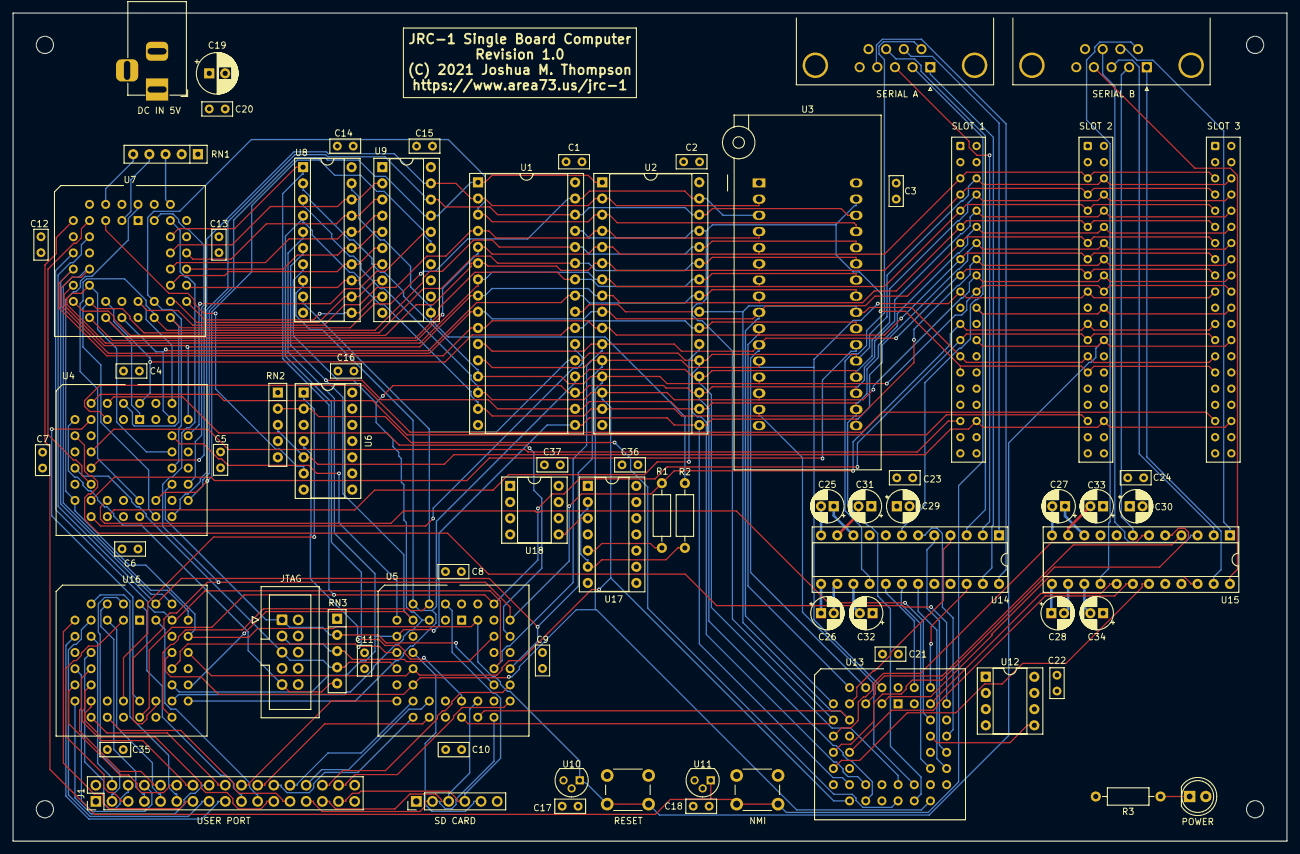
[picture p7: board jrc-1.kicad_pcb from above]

Board: 4 copper layers, 200.0 x 130.0 mm, 77 parts (0 on the bottom side), 147 nets.

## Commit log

2021-09-03 Design files for JIGL custom CPLD, and beginning board schematic
    [core.sch, jrc-1.kicad_pcb, jrc-1.sch]
2021-12-11 RC1 of schematic and initial board layout
    [clock.sch, core.sch, cpu.sch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]
2021-12-11 Use custom footprint for slots to get more favorable pin numbering for layout purposes.
    [jrc-1.kicad_pcb, ports.sch]
2021-12-24 Fix footprint for RESET and NMI button handlers Fix symbol for '573 latch
    [cpu.sch, jrc-1.kicad_pcb, misc.sch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]
2021-12-26 Initial firmware port from COLE-1+/COLE-2.
    [jrc-1.cfg]
2021-12-28 Split bios.s into smaller, more manageable files.
    Adjust the memory map configuration so that the area in bank $10 below
    the $F800 ROM is now used for the OS code, leaving the rest free for
    built-in applications and whatnot.
    [jrc-1.cfg]
2021-12-28 Move syscall dispatcher up to the OSROM area to give more room for the dispatch cable to grow.
2021-12-29 Flesh out more of the device manager Register the serial ports as devices Merge vt100_console.s into console.s Console now attaches to serial devices via device manager Moved getc_serialX and putc_se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
2021-12-29 Register the CONSOLE device as device #0 Move print_hex and print_decimal8 out of console.s and into util.s Make console_attach return an error if you try to attach the console to itself
2022-01-09 Change monitor's address parsing to work more like the GS monitor. Addresses are now BB/XXYY, and addresses without a bank byte will use the current bank byte value.
    Remove '>' from monitor prompt
2022-01-09 Allow commands to be upper or lower case.
2022-01-09 Add scaffolding for a GS-style mini assembler.
2022-01-09 Rip out all the character device definitions, and streamline the console calls.
2022-01-10 Beginning of reorganization of syscalls:
    - Move dispatch code to interrupts.s; syscalls.s is now just the table
    - Add some new console calls
    - Remove device manager calls
    - Add SPI calls
2022-01-10 Separate interrupt and normal OS contexts so that interrupts run with the data bank in bank 0, but the rest of the OS runs with the data bank set to the SYSRAM bank (normally $01). This configuration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
2022-01-11 Fix code to use far addresing for 65SPI registers now that DB is no onger in bank 0 outside of interrupts.
2022-01-12 Switch to external clock input, which is bodge wired to VIA PB7. This allows us to init SD cards at a slower rate than PHI2.
2022-01-12 Make JR/OS initialization partially work again. Fixed up old 8-bit code in a number of places as well.
    Fix SD card driver init and status calls. They now work...usually.
2022-01-12 Add ability to switch between slow (400 kHZ) and fast (phi2) SPI clocks. The default is back to fast mode, with the SD card driver temporarily setting slow mode during card initialization.
2022-01-12 Add read/write block calls (not currently working)
2022-01-13 WIP JR/OS device enumeration
2022-01-16 Add print_decimal32 routine
2022-01-16 Fix buggy zero suppression in print_decimal32
2022-01-16 Print device size during device scan
2022-01-17 Remove device driver mount call Add retry logic to sdc_init Fix param byte counts for JR/OS syscalls.
2022-02-21 Move UART direct page allocations into directpage.s
2022-02-23 Move all buffers from into the SYSDATA segment, freeing up about 1.5k more bank 0 space.
    [jrc-1.cfg]
2022-02-23 Move syscall table to its own segment at a fixed location.
    [jrc-1.cfg]
2022-02-24 Refactor syscall dispatching to put a pointer to the caller's params frame into the global zp location "params", instead of just supporting 0 or 1 parameter.
2022-03-13 Add a device manager subsystem to manage character and block devices. At the moment only the SPI and SDCARD drivers have been converted to this new framework; serial and console drivers will follow.
2022-03-13 Remove OPEN and CLOSE for block devices and add a MOUNT call.
    Update the sdcard driver so that STARTUP always succeeds, making sure
    the driver is installed even if no card is present at boot time. A
    subsequent MOUNT call can be used to initialize the card.
2022-03-14 Add bootup device scan and volume scans.
2022-05-08 Move print_decimal8 function into the startup code, as that is the only thing using it. The rest of util.s now belongs to the monitor.
2022-05-18 Update print_decimal32 to use stack local variables instead of memory in SYDATA, and also make it callable with any register widths
2022-05-19 Replace original print_decimal32 with format_decimal, which renders to an output buffer instead of directly to console, and supports more formatting options.
2022-09-11 Adjust T1 constant for 400 kHz SPI clock generation to account for the board now running at 8 MHz
2022-09-19 Rename SYSDATA segment to BSS
    [jrc-1.cfg]
2022-10-19 Add memory management subsystem and associated syscalls.
    Add monitor 'h' command for dumping the internal memory manager handle lists.
    [jrc-1.cfg]
2022-12-31 Fix typo in comment
    [jrc-1.cfg]
2023-01-01 Rework how devices are handled, slightly. For internal hardware that needs initialized early (e.g. UART and VIA) the initi function is now separate from the function that registers the device drivers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
    This is the beginnings of a work to move the console and serial ports
    into regular char device drivers, instead of having their own dedicated
    syscalls.
2023-01-02 Remove all in-kernel calls to the console driver and replace them with new _kputc and _kprint macros. internally both call putc_seriala directly. These new macros are only used in the actual kernel c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
2023-03-08 Remove existing DOS skeleton code and device manager syscalls in prep for switch to new device model.
2023-03-08 Add kernel heap management code
    [jrc-1.cfg]
2023-03-08 Add skeletal framework for process support and scheduler
2023-03-09 Reduce OS stack to 256 bytes and fix USERRAM to not overlap the heap
    [jrc-1.cfg]
2023-04-06 Mega-patch:
    - New driver architecture
    - All old console/serial port syscalls removed
    - Add initial support for filesystem and FS syscalls
    - Update monitor to open /dev/console as stdin,stdout,stderr
    - stdlib functions that access console now use stdin and stdout

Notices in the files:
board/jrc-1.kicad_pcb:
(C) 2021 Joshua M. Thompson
